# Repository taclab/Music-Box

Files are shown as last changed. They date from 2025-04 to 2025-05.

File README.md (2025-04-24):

# Music-Box: NFC-Driven Music Player

An interactive music player that uses NFC cards to control playback. Perfect for children or interactive installations where physical objects trigger audio content.

This project is a fork of [Wilksy's Asher Music Box](https://github.com/wilksy/Asher-Music-Box), originally described in the ["Tiny Tonie" blog post](https://wilksy.com/tiny-tonie/). The original project was created as an alternative to commercial "Toniebox" audio players, focusing on providing a more affordable and customizable solution.

## Features

- Play audio tracks by tapping NFC cards
- Control volume with special NFC cards
- Musical Chairs mode that randomly pauses music
- End-of-track detection via DFPlayer's busy pin
- Multiple card detection warning
- Customizable sound effects for different actions

## Hardware Components

- [Fresh'n Rebel ROCKBOX CUBE](https://www.amazon.fr/Enceinte-Bluetooth-Rockbox-Fabric-arm%C3%A9e/dp/B0173HSDJW)
- [Adafruit Feather HUZZAH with ESP8266](https://www.adafruit.com/product/2821)
- [PN532 NFC/RFID Reader Module](https://www.banggood.com/PN532-NFC-RFID-Module-V3-Reader-Writer-Breakout-Board-For-Android-p-1213484.html)
- [DFRobot DFPlayer Mini](https://www.digikey.co.uk/product-detail/en/dfrobot/DFR0299/1738-1041-ND/6588463)
- MicroSD card for audio storage
- 3.7V LiPo battery
- 3D printed case (STL files included)

## Project Setup

### PlatformIO Setup

This project uses PlatformIO for easy dependency management and deployment:

1. Install [Visual Studio Code](https://code.visualstudio.com/)
2. Install the [PlatformIO extension](https://platformio.org/install/ide?install=vscode)
3. Clone this repository
4. Open the project folder in VS Code
5. Build and upload using the PlatformIO toolbar

### Arduino IDE Setup

If you prefer Arduino IDE:

1. Rename `main.cpp` to `main.ino`
2. Install required libraries through the Library Manager:
   - DFRobotDFPlayerMini
   - PN532_I2C
   - PN532

### Wiring

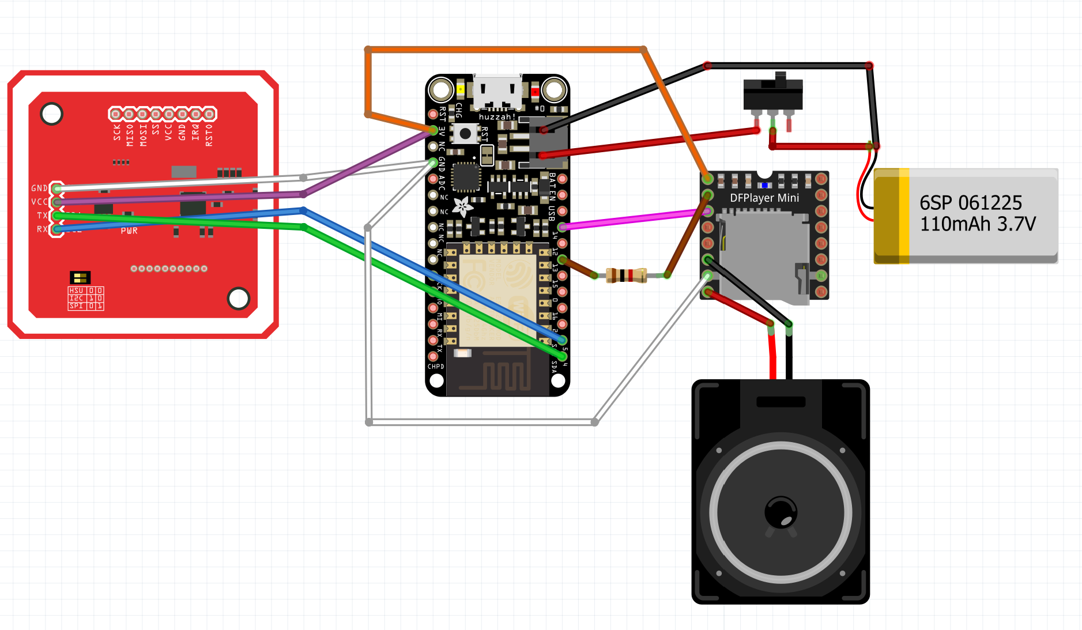
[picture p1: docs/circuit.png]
circuit


Connect components as follows:

| ESP8266 | PN532 NFC | DFPlayer Mini |
|---|---|---|
| 3.3V | VCC | - |
| GND | GND | GND |
| SDA | SDA | - |
| SCL | SCL | - |
| 3.3V | - | VCC |
| GPIO14  | - | RX |
| GPIO13  | - | TX |
| GPIO16  | - | BUSY |

## Audio File Setup

1. Format a microSD card as FAT32
2. Create folders:
   - `/01` for system sounds (connect, disconnect, error sounds)
   - `/02` for music tracks
3. Add MP3 files numbered sequentially (001.mp3, 002.mp3, etc.)
```
.
├── 01
│   ├── 001.mp3 # Valid music card
│   ├── 002.mp3 # Startup sound
│   ├── 004.mp3 # Card not recognised
│   ├── 005.mp3 # Card has been removed, play a nice sound
│   └── 006.mp3 # Volume adjust
│   └── 007.mp3 # Multiple cards detected, play a fun warning sound
└── 02
    ├── 001.mp3 # Sound
    └── 00X.mp3
```

## NFC Card Configuration

Edit the `cards.h` file to register your NFC cards:

- Control cards: Volume control, Musical Chairs mode toggle
- Track cards: Each triggers a specific audio track

To add cards, scan them with the device while monitoring the serial output, then add their IDs to the appropriate array in `cards.h`.

## 3D Printed Case

STL files for enclosure components are included in the `/docs/stl` directory. The design is compatible with a "rebel rock and roll cube" with internal components replaced.

## License

[MIT License](LICENSE)

## Acknowledgements

- Based on the "Asher Music Box" project by [Wilksy (2020)](https://wilksy.com/tiny-tonie/)
- Original project repository: [github.com/wilksy/Asher-Music-Box](https://github.com/wilksy/Asher-Music-Box)
- Updated with PlatformIO support and library improvements
- Enhanced with additional documentation and code

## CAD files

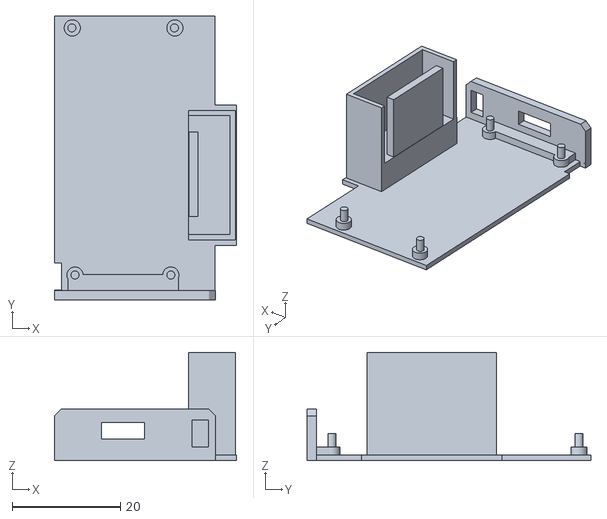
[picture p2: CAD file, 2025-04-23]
docs/stl/Music Box Circuit Holder Single.stl
33.7 x 52.5 x 20.0

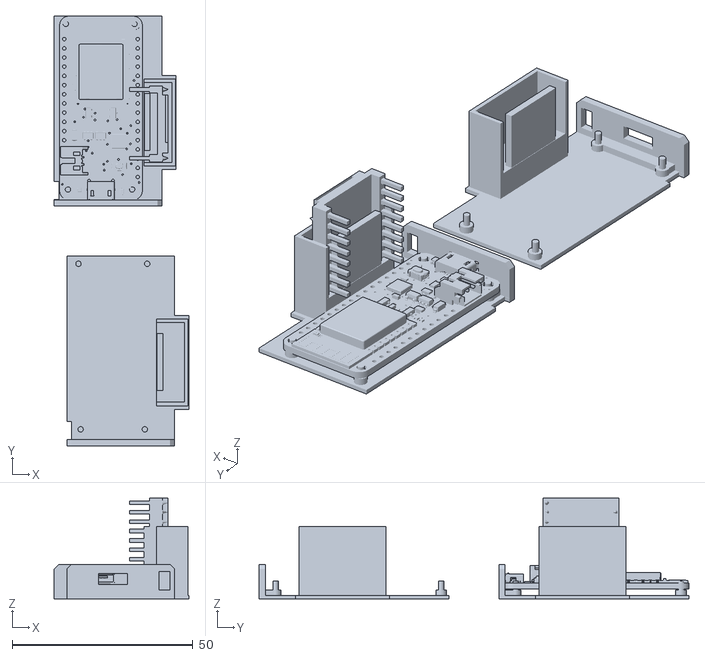
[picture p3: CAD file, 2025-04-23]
docs/stl/Music Box Circuit Holder.stl
37.2 x 118.8 x 27.9

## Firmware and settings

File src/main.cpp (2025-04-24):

/*!************************************************************************

      Asher Music Box 2
      Wilksy 2020
      1_6 clean up vars
      updated Easy DFplayer to from 1.1.12 to 1.2
      Implemented end of track detection using Busy pin 
      Implemented Musical Chairs mode

**************************************************************************/


/*************NFC Reader****************************************************/
#include <Wire.h>
#include <PN532_I2C.h>
#include <PN532.h>

#include <ESP8266WiFi.h>
PN532_I2C pn532i2c(Wire); // Im using I2c for commuication, so default SDA/SLA pins in play(cant be changed on esp8266 they are BB'd).
PN532 nfc(pn532i2c);
/**************************************************************************/

/*************AudioPlayer****************************************************/
#include "Arduino.h"
#include "SoftwareSerial.h"
SoftwareSerial mySoftwareSerial(14, 13); // RX, TX Serial Comms using Software Serial RX --> TX, TX --> RX
#define AudioBusyPin 16

#include "DFRobotDFPlayerMini.h"
DFRobotDFPlayerMini myMP3;
/*********************************************************************/

/*************Wifi****************************************************/
#include <ESP8266WiFi.h> // I will expand on network functionaity later, for now i need this to turn off wifi for power savings
/*********************************************************************/

/*************Card Definitions*******************************************/
#include "cards.h" // include the card definitions and functions

// Program Control Vars
struct adminSettings {
  uint8_t VolumeRoundRobin[4] = {10, 15, 20, 25}; //volume is adjusted on a round robin
  uint8_t initVolume = 2; // initial volume level (in array)
  uint8_t DFPlayerProcessDelay = 100; //time for the Audio Player to reset
  bool isCardPresent = false;
  bool isValidCardPresent = false;
  bool isMultipleCardsPresent = false;
  uint8_t PlayingType = 0; //0-nothing,1-music,2-story.
  bool isMusicalChairsMode = false;
  unsigned long NextStatueTime = 0;
  unsigned long MilliStartPlaytime = 0;
  unsigned long ReadStateMillis = 0;
  unsigned long ReadStateDelay = 250;
  unsigned long LastCardMillis = 0;
  unsigned long LastCardThreshold = 100; // Time to wait until we register a card as being removed
  unsigned long LastProcessedEvent = 0;
  String CurrentCardUID = "";
  String PreviousCardUID = "";
};

adminSettings CurrentSettings;


void SetnewStatueTime() {
  //return a random time until next status time!
  //at least 10 seconds away and not more than 30
  int randomNumber = random(10, 30);
  CurrentSettings.NextStatueTime = (millis() + (randomNumber * 1000));
}

void ProcessEvent(String UID, int Action) {
  //Action 1 = card found, 2 = multiple cards found, 3 = valid card

  //block events happening too fast and causing the DFplayer to have a fit and reset

  if ((millis() - CurrentSettings.LastProcessedEvent) < CurrentSettings.DFPlayerProcessDelay) {
    //woah there buddy
    delay(CurrentSettings.DFPlayerProcessDelay);
  }
  CurrentSettings.LastProcessedEvent = millis();
  //myMP3.pause();//seems i can do without this pause here now.
  myMP3.stop();
  delay(20); //pause and audio and wait for DFplayer to be happy


  if (Action == 1) { //a card has been removed, play a nice sound
    CurrentSettings.PlayingType = 0;
    myMP3.playFolder(1, 5);
    Serial.println("Card Removed");
    return;
  }
  if (Action == 2) { //multiple cards detected, play a fun warning sound
    CurrentSettings.PlayingType = 0;
    myMP3.playFolder(1, 7);
    Serial.println("Multiple Cards" + UID);
    return;
  }

  if (Action == 3) { //A valid card presented event, process it.
    int PTResult = -1;
    PTResult = isControlCard(UID); //It's a control card, at the moment thats just a volume control card
    if (PTResult >= 0) { //found a control card

      if (PTResult == 0 || PTResult == 1) { // volume card
        CurrentSettings.initVolume++;
        if (CurrentSettings.initVolume > 3) {
          CurrentSettings.initVolume = 0;
        }
        myMP3.volume(CurrentSettings.VolumeRoundRobin[CurrentSettings.initVolume]);
        delay (CurrentSettings.DFPlayerProcessDelay);
        myMP3.playFolder(1, 6);
        Serial.println("Volume Adjust - ");
        Serial.print(CurrentSettings.initVolume);
        Serial.println("");
        return;
      }
      if (PTResult == 2 ) { // Statue card
        //toggle statue mode
        CurrentSettings.isMusicalChairsMode = !CurrentSettings.isMusicalChairsMode;
        //tell debug
        if (CurrentSettings.isMusicalChairsMode) {
                myMP3.playFolder(1, 1);      
          Serial.println("Statue on");
        }
        else {
          Serial.println("Statue off");
          myMP3.playFolder(1, 5);
        }
        return;
      }

    }

    PTResult = isTrackCard(UID);
    if (PTResult >= 0) { //Found a valid music card / play it!
      myMP3.playFolder(1, 1);
      delay(610); //ugly delaky while card noise playsouts. this was adjusted until it 'felt' right.
      myMP3.stop();
      delay (CurrentSettings.DFPlayerProcessDelay);
      myMP3.playFolder(2, PTResult);
      Serial.println("Play Track - ");
      Serial.print(UID);
      Serial.println("PTResult - ");
      Serial.print(PTResult);
      Serial.println("");
      CurrentSettings.PlayingType = 1;
      CurrentSettings.MilliStartPlaytime = millis();
      if (CurrentSettings.isMusicalChairsMode) {
        SetnewStatueTime();
      }
      return;
    }

    //card not recognised, player fun sound
    Serial.println("Card not found - ");
    Serial.print(UID);
    Serial.println("");
    myMP3.playFolder(1, 4);
    return;
  }

}




void setup(void) {


  randomSeed(analogRead(A0)); // read noise from an Analogue GIO for the random number generator


  // turn off wifi to reduce battery drain until app is ready
  WiFi.disconnect();
  WiFi.mode(WIFI_OFF);
  WiFi.forceSleepBegin();

  // Serial for debugging // remove when finished
  Serial.begin(115200);

  // Afficher un message de démarrage
  Serial.println(F("=== Music Box Booting ==="));
  Serial.println(F("Initialisation des composants..."));

  /*************Start Audio Player****************************************************/
  mySoftwareSerial.begin(9600);
  myMP3.begin(mySoftwareSerial);
  pinMode(16, INPUT);

  Serial.println(F("Audio online."));
  delay(750); //give time for things to settle and have a cup of tea.
  myMP3.volume(CurrentSettings.VolumeRoundRobin[CurrentSettings.initVolume]);  //Set default volume.
  myMP3.EQ(DFPLAYER_EQ_NORMAL); // Set default EQ
  // EQ_NORMAL       = 0;EQ_POP          = 1;EQ_ROCK         = 2;EQ_JAZZ         = 3;EQ_CLASSIC      = 4; EQ_BASE         = 5;

  /*********************************************************************/

  /*************Start NFC Reader***************************************/
  nfc.begin();

  uint32_t versiondata = nfc.getFirmwareVersion();
  if (! versiondata) {
    Serial.print("PN53x NOT FOUND");
    while (true) {
      delay(0); // Keep ESP8266 watch dog happy.
    }
  }

  // configure read RFID tags
  nfc.SAMConfig();
  nfc.setPassiveActivationRetries(0x1); // set NFC read attempts to 1. So we can read up to 2 cards and not have the nfc block code.
  Serial.println("NFC OK");

  /*********************************************************************/

  // Startup Complete
  Serial.println("All Systems go...");

  CurrentSettings.ReadStateMillis = millis();

  // Startup sound
  myMP3.playFolder(1, 2);
}


void loop(void) {

  String tmptag  = "";
  uint8_t success;
  uint8_t uid[] = { 0, 0, 0, 0, 0, 0, 0 };  // UID Buffer
  uint8_t uidLength;                        // Length of the UID (4 or 7 bytes)

  // Is an NFC card Present
  success = nfc.readPassiveTargetID(PN532_MIFARE_ISO14443A, uid, &uidLength);


  //process nfc card touch

  // If anybody is thinking why im doing it this way.
  // 1. This is non-blocking
  // 2. It allows for processing for up to 2 card (not implemented yet)
  // 3. This is the first working way I could process a new/removed card well.
  if (success) {
    //hold a flag if a card is present
    CurrentSettings.isCardPresent = true;

    for (uint8_t i = 0; i < uidLength; i++) {
      tmptag.concat(uid[i]); //convert hex card id to a string (yes i know, strings!!)
    }
    CurrentSettings.CurrentCardUID = tmptag;
    if (CurrentSettings.PreviousCardUID == "") {
      CurrentSettings.PreviousCardUID = tmptag; //first time a card has been presented
    }

    if (CurrentSettings.PreviousCardUID == tmptag) {//assume single card
      if (!CurrentSettings.isValidCardPresent) {
        CurrentSettings.isValidCardPresent = true;
        CurrentSettings.isMultipleCardsPresent = false;
        ProcessEvent(tmptag, 3);
      }
    } else {
      if (!CurrentSettings.isMultipleCardsPresent) { //assume Multiple Cards
        CurrentSettings.isValidCardPresent = false;
        CurrentSettings.isMultipleCardsPresent = true;
        ProcessEvent("", 2);
      }
    }
    CurrentSettings.LastCardMillis = millis();
    CurrentSettings.PreviousCardUID = tmptag;
  }

  //check for a card removed
  if (((millis() - CurrentSettings.LastCardMillis) > CurrentSettings.LastCardThreshold) && CurrentSettings.isCardPresent) {
    CurrentSettings.PreviousCardUID = "";//CurrentCardUID;
    CurrentSettings.CurrentCardUID = "";
    CurrentSettings.isCardPresent = false;
    CurrentSettings.isValidCardPresent = false;
    CurrentSettings.isMultipleCardsPresent = false;
    ProcessEvent("", 1);
  }

  //check for playback stopped
  if ((millis() -  CurrentSettings.ReadStateMillis) >  CurrentSettings.ReadStateDelay) {
    //we also wait two seconds after a track has started until we check to see if it has ended
    if ((millis() - CurrentSettings.MilliStartPlaytime) > 2000 ) {

      CurrentSettings.ReadStateMillis = millis();
      int IsAudioPlaying = digitalRead(AudioBusyPin);
      if (IsAudioPlaying == 1 && CurrentSettings.PlayingType > 0) {
        Serial.println("Play has stopped");
        CurrentSettings.PlayingType = 0;
      }
    }
  }

  //check for Musical Chairs /Statue mode
  //we also wait two seconds after a track has started until we check to see if we need an eent
  if ((millis() - CurrentSettings.MilliStartPlaytime) > 2000 ) {
    if ( CurrentSettings.PlayingType > 0 && CurrentSettings.isMusicalChairsMode) {
      long timetillpause = (CurrentSettings.NextStatueTime - millis());
                            Serial.print("Time till pause  ");
                            Serial.println(timetillpause);
      if  (timetillpause < 0 ) { //time for a pause. min 3 sec max  7 
          int randomNumber = random(3, 6); 
          SetnewStatueTime() ; 
          Serial.println("Pause...");
          myMP3.pause();     
          delay(1000* randomNumber);
          Serial.println("Resume...");
          myMP3.start();
                   
      }


    }
  }






}

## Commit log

2025-04-23 Add initial PlatformIO project structure and configuration files
    [Music Box Circuit Holder.stl]
2025-04-23 Remove unused STL and source files for Music Box project
    [Music Box Circuit Holder.stl]
2025-04-23 Add STL file for Music Box circuit holder design
    [Music Box Circuit Holder Single.stl]
2025-04-24 Update README with project details, features, and setup instructions; add circuit diagram and STL files for circuit holder
    [Music Box Circuit Holder Single.stl, Music Box Circuit Holder.stl, circuit.fzz]
2025-04-24 Fix README wording and update circuit diagram image
2025-05-27 Update circuit diagram files for improved clarity and accuracy
    [circuit.fzz]
